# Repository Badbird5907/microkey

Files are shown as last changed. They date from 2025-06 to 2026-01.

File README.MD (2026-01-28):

# MicroKey
[Video Demo](https://youtube.com/shorts/Fg3U53FJ8HM)

Firmware can be found [here](https://github.com/Badbird5907/pico-fido-microkey)

This is a FIDO2 security key! It utilizes the RP2350A and [PicoKeys](https://picokeys.com) to implement FIDO2 U2F functionality! Unlike most picokeys, it uses a gold disc like the yubikey to detect touch instead of a tactile button.

I made this project because I saw the RP2350 could be used as a FIDO2 device with firmware like PicoKeys, and I couldn't find a yubikey-like device designed for PicoKeys. All the devices that were used were devboards, with tactile buttons and long USB cables.

front
back





# BOM
|Manufacturer |Description |Quantity|Unit Price($)|Ext.Price($)|Link |
|---|---|---|---|---|---|
|UNI-ROYAL(Uniroyal Elec) |62.5mW Thick Film Resistor 50V ±100ppm/℃ ±1% 1kΩ 0402 Chip Resistor - Surface Mount ROHS |100 |0.0006 |0.06 |https://lcsc.com/product-detail/chip-resistor-surface-mount_uni-royal-uniroyal-elec-0402wgf1001tce_C11702.html |
|Samsung Electro-Mechanics |16V 100nF X7R ±10% 0402 Multilayer Ceramic Capacitors MLCC - SMD/SMT ROHS |100 |0.0012 |0.12 |https://lcsc.com/product-detail/multilayer-ceramic-capacitors-mlcc-smd-smt_samsung-electro-mechanics-cl05b104ko5nnnc_C1525.html |
|FH (Guangdong Fenghua Advanced Tech)  |50V 15pF C0G ±5% 0402 Multilayer Ceramic Capacitors MLCC - SMD/SMT ROHS |100 |0.001 |0.1 |https://lcsc.com/product-detail/multilayer-ceramic-capacitors-mlcc-smd-smt_fh-guangdong-fenghua-advanced-tech-0402cg150j500nt_C1548.html|
|Samsung Electro-Mechanics |25V 10uF X5R ±10% 0805 Multilayer Ceramic Capacitors MLCC - SMD/SMT ROHS |20 |0.011 |0.22 |https://lcsc.com/product-detail/multilayer-ceramic-capacitors-mlcc-smd-smt_samsung-electro-mechanics-cl21a106kaynnne_C15850.html |
|Abracon LLC |SMD3225-4P Crystals ROHS |1 |0.3731 |0.37 |https://lcsc.com/product-detail/crystals_abracon-llc-abm8-272-t3_C20625731.html |
|Samsung Electro-Mechanics |10V 4.7uF X5R ±20% 0402 Multilayer Ceramic Capacitors MLCC - SMD/SMT ROHS |50 |0.0052 |0.26 |https://lcsc.com/product-detail/multilayer-ceramic-capacitors-mlcc-smd-smt_samsung-electro-mechanics-cl05a475mp5nrnc_C23733.html |
|UNI-ROYAL(Uniroyal Elec) |62.5mW Thick Film Resistor 50V ±100ppm/℃ ±1% 220Ω 0402 Chip Resistor - Surface Mount ROHS |100 |0.0006 |0.06 |https://lcsc.com/product-detail/chip-resistor-surface-mount_uni-royal-uniroyal-elec-0402wgf2200tce_C25091.html |
|UNI-ROYAL(Uniroyal Elec) |62.5mW Thick Film Resistor 50V ±100ppm/℃ ±1% 27Ω 0402 Chip Resistor - Surface Mount ROHS |100 |0.0006 |0.06 |https://lcsc.com/product-detail/chip-resistor-surface-mount_uni-royal-uniroyal-elec-0402wgf270jtce_C25100.html |
|UNI-ROYAL(Uniroyal Elec) |62.5mW Thick Film Resistor 50V ±100ppm/℃ ±1% 33Ω 0402 Chip Resistor - Surface Mount ROHS |100 |0.0006 |0.06 |https://lcsc.com/product-detail/chip-resistor-surface-mount_uni-royal-uniroyal-elec-0402wgf330jtce_C25105.html |
|UNI-ROYAL(Uniroyal Elec) |62.5mW Thick Film Resistor 50V ±100ppm/℃ ±1% 10kΩ 0402 Chip Resistor - Surface Mount ROHS |100 |0.0006 |0.06 |https://lcsc.com/product-detail/chip-resistor-surface-mount_uni-royal-uniroyal-elec-0402wgf1002tce_C25744.html |
|UNI-ROYAL(Uniroyal Elec) |62.5mW Thick Film Resistor 50V ±100ppm/℃ ±1% 5.1kΩ 0402 Chip Resistor - Surface Mount ROHS |100 |0.0005 |0.05 |https://lcsc.com/product-detail/chip-resistor-surface-mount_uni-royal-uniroyal-elec-0402wgf5101tce_C25905.html |
|Winbond Elec |16Mbit SPI 133MHz USON-8-EP(2x3) NOR FLASH ROHS |1 |0.6178 |0.62 |https://lcsc.com/product-detail/nor-flash_winbond-elec-w25q16jvuxiq_C2843335.html |
|Texas Instruments |65dB@(100kHz) 300mA Fixed 3.3V Positive 6V SOT-23-5 Voltage Regulators - Linear, Low Drop Out (LDO) Regulators ROHS|5 |0.201 |1.01 |https://lcsc.com/product-detail/voltage-regulators-linear-low-drop-out-ldo-regulators_texas-instruments-tps7a2033pdbvr_C2862740.html |
|XKB Connection |5A 1 12P Male -55℃~+85℃ Type-C SMD USB Connectors ROHS |1 |1.0428 |1.04 |https://lcsc.com/product-detail/usb-connectors_xkb-connection-u261-121n-4bs2s_C2879827.html |
|Raspberry Pi |QFN-60-EP(7x7) Microcontrollers (MCU/MPU/SOC) ROHS |1 |1.6544 |1.65 |https://lcsc.com/product-detail/microcontrollers-mcu-mpu-soc_raspberry-pi-rp2350a_C42411118.html |
|Abracon LLC |0806 Power Inductors ROHS |5 |0.2584 |` |https://lcsc.com/product-detail/power-inductors_abracon-llc-aota-b201610s3r3-101-t_C42411119.html |
|Kingbright |SMD3528-4P RGB LEDs ROHS |1 |1.6213 |1.62 |https://lcsc.com/product-detail/rgb-leds_kingbright-aaa3528rbgs-08-09_C6851380.html |
|Shipping | | | |11.71 | |
|Handling Fee | | | |3 | |
|PCB (expensive bc ENIG + edge plating)| | | |67.28 | |
|Stencil | | | |7.48 | |
|JLC Shipping | | | |7.78 | |
|TOTAL | | | |104.61 | |

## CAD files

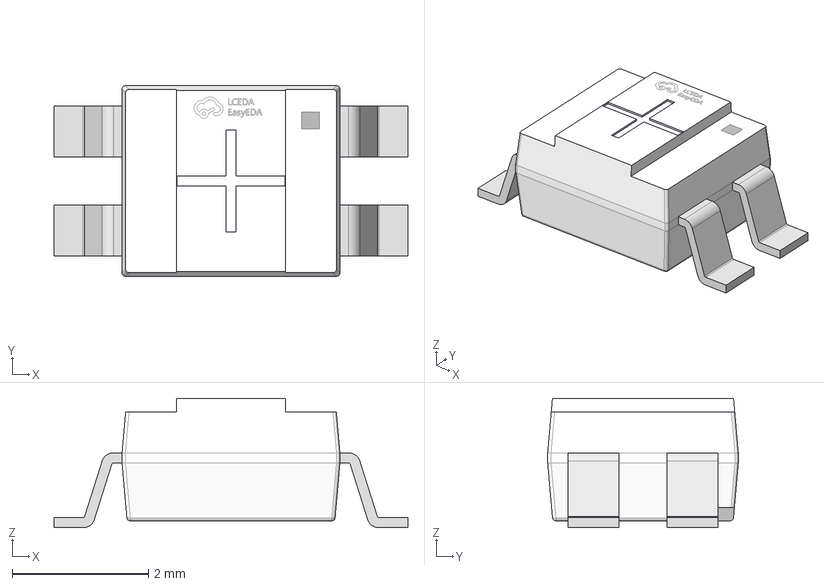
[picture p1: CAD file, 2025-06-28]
PCB/Components/LED-SMD_4P-L3.2-W2.8_XZMDKCBDDG45S-9.step
5.20 x 2.80 x 1.90 mm

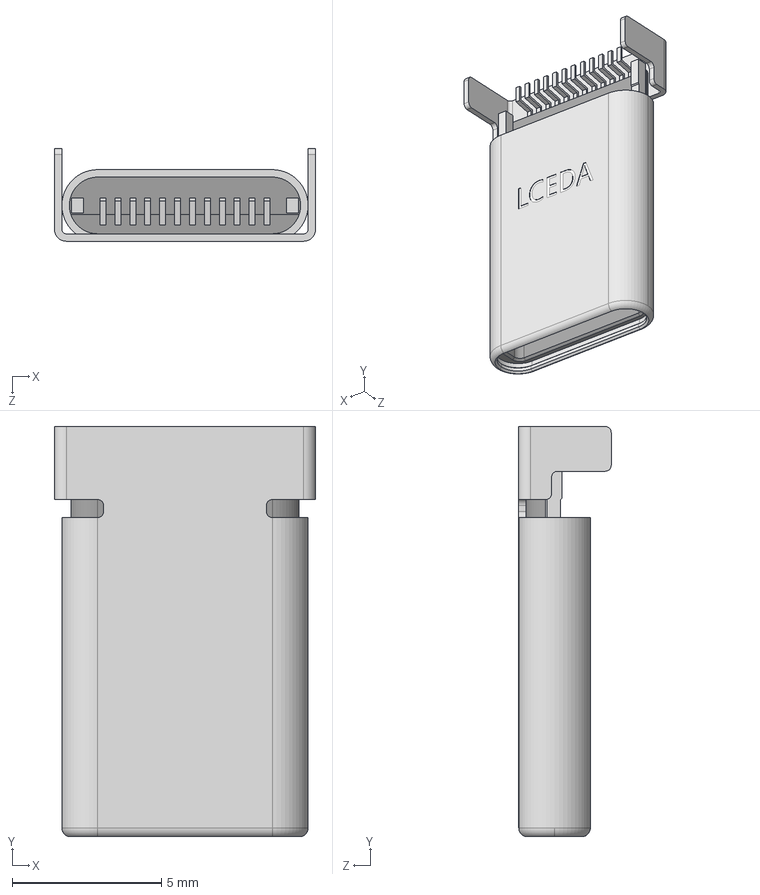
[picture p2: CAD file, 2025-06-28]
PCB/Components/USB-C-SMD_U261-121N-4BS2S.step
8.75 x 13.7 x 3.10 mm

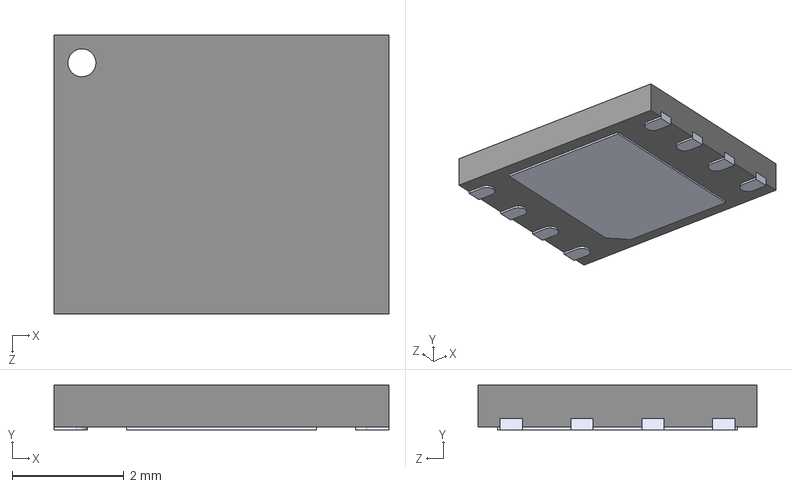
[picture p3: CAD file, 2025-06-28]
PCB/Components/W25Q16JVZPIQ.step
6.00 x 0.8 x 5.00 mm

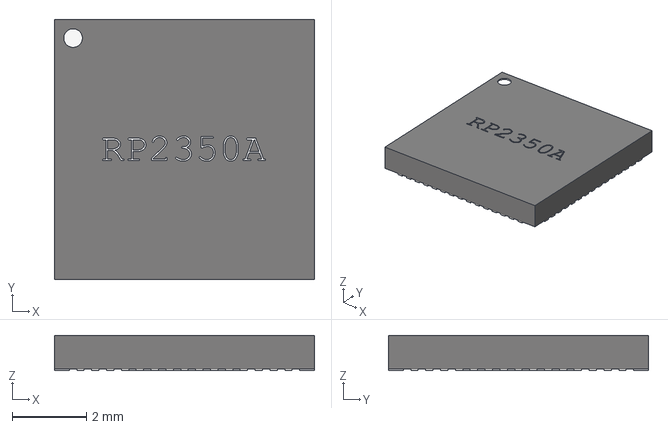
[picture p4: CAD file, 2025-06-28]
PCB/Components/RP2350_QFN60.step
7.00 x 7.00 x 0.95 mm

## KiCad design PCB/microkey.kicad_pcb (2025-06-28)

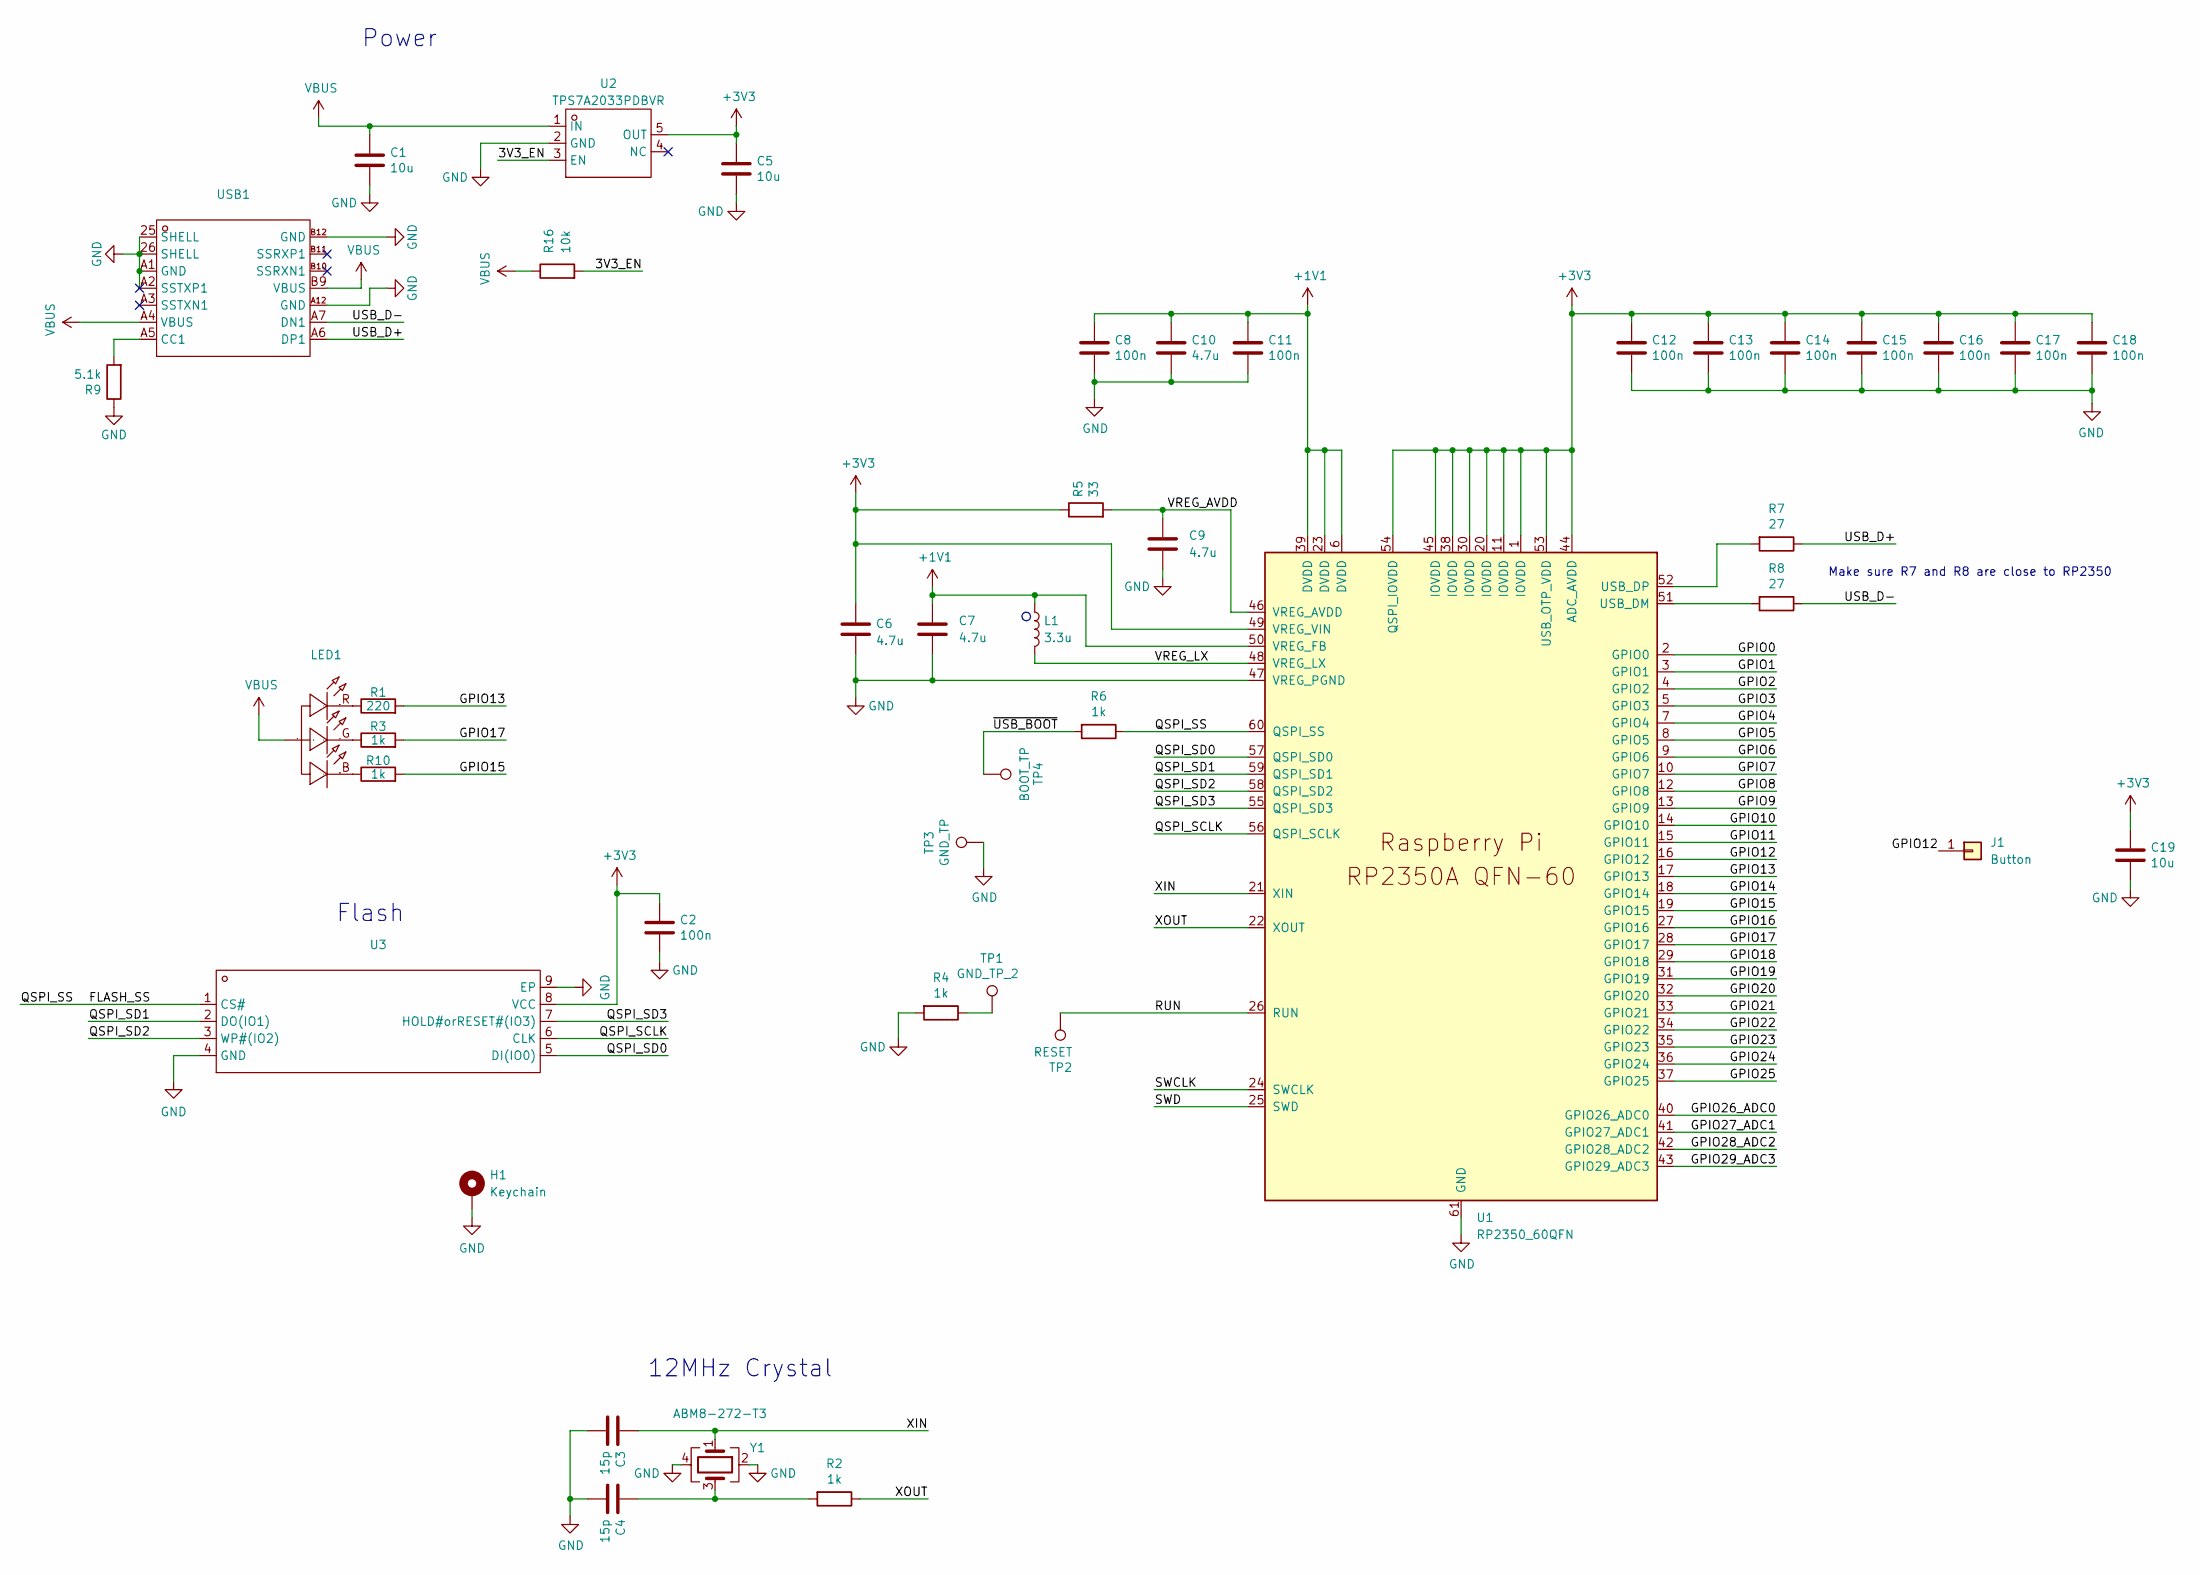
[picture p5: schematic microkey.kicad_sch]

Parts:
C1, C5, C19: 10u; C_0805_2012Metric
C2, C8, C11, C12, C13, C14, C15, C16, C17, C18: 100n; C_0402_1005Metric
C3, C4: 15p; C_0402_1005Metric
C6, C7: 4.7u; C_0402_1005Metric_small_pads
C9, C10: 4.7u; C_0402_1005Metric
H1: Keychain
J1: Button
L1: 3.3u; L_pol_2016
LED1: LED-SMD_4P-L3.2-W2.8_XZMDKCBDDG45S-9; Manufacturer Part AAA3528RBGS/08-09; LCSC Part Name AAA3528RBGS/08-09
R1: 220; R_0402_1005Metric
R2, R3, R4, R6, R10: 1k; R_0402_1005Metric
R5: 33; R_0402_1005Metric
R7, R8: 27; R_0402_1005Metric
R9: 5.1k; R_0402_1005Metric
R16: 10k; R_0402_1005Metric
TP1: GND_TP_2; TestPoint_Pad_D1.0mm
TP2: RESET; TestPoint_Pad_D1.0mm
TP3: GND_TP; TestPoint_Pad_D1.0mm
TP4: BOOT_TP; TestPoint_Pad_D1.0mm
U1: RP2350_60QFN; RP2350-QFN-60-1EP_7x7_P0.4mm_EP3.4x3.4mm_ThermalVias
U2: TPS7A2033PDBVR; SOT-23-5_L2.9-W1.6-P0.95-LS2.8-BR; Manufacturer Part TPS7A2033PDBVR; LCSC Part Name 具有高 PSRR 的 300mA、超低噪声、低 IQ、低压降 (LDO) 线性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
U3: USON-8_L3.0-W2.0-P0.50-BL-EP; Manufacturer Part W25Q16JVUXIQ; LCSC Part Name W25Q16JVUXIQ
USB1: USB-C-SMD_U261-121N-4BS2S; Manufacturer Part U261-121N-4BS2S; LCSC Part Name Type-C 公
Y1: ABM8-272-T3; Crystal_SMD_3225-4Pin_3.2x2.5mm

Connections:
+1V1: C7.1, C8.1, C10.1, C11.1, L1.1, U1.6 (DVDD), U1.23 (DVDD), U1.39 (DVDD), U1.50 (VREG_FB)
+3V3: C2.1, C5.1, C6.1, C12.1, C13.1, C14.1, C15.1, C16.1, C17.1, C18.1, C19.1, R5.1, U1.1 (IOVDD), U1.11 (IOVDD), U1.20 (IOVDD), U1.30 (IOVDD), U1.38 (IOVDD), U1.44 (ADC_AVDD), U1.45 (IOVDD), U1.49 (VREG_VIN), U1.53 (USB_OTP_VDD), U1.54 (QSPI_IOVDD), U2.5 (OUT), U3.8 (VCC)
/3V3_EN: R16.2, U2.3 (EN)
/FLASH_SS: R6.1, U1.60 (QSPI_SS), U3.1 (CS#)
/GPIO0: U1.2 (GPIO0)
/GPIO1: U1.3 (GPIO1)
/GPIO2: U1.4 (GPIO2)
/GPIO3: U1.5 (GPIO3)
/GPIO4: U1.7 (GPIO4)
/GPIO5: U1.8 (GPIO5)
/GPIO6: U1.9 (GPIO6)
/GPIO7: U1.10 (GPIO7)
/GPIO8: U1.12 (GPIO8)
/GPIO9: U1.13 (GPIO9)
/GPIO10: U1.14 (GPIO10)
/GPIO11: U1.15 (GPIO11)
/GPIO12: J1.1, U1.16 (GPIO12)
/GPIO13: R1.2, U1.17 (GPIO13)
/GPIO14: U1.18 (GPIO14)
/GPIO15: R10.2, U1.19 (GPIO15)
/GPIO16: U1.27 (GPIO16)
/GPIO17: R3.2, U1.28 (GPIO17)
/GPIO18: U1.29 (GPIO18)
/GPIO19: U1.31 (GPIO19)
/GPIO20: U1.32 (GPIO20)
/GPIO21: U1.33 (GPIO21)
/GPIO22: U1.34 (GPIO22)
/GPIO23: U1.35 (GPIO23)
/GPIO24: U1.36 (GPIO24)
/GPIO25: U1.37 (GPIO25)
/GPIO26_ADC0: U1.40 (GPIO26_ADC0)
/GPIO27_ADC1: U1.41 (GPIO27_ADC1)
/GPIO28_ADC2: U1.42 (GPIO28_ADC2)
/GPIO29_ADC3: U1.43 (GPIO29_ADC3)
/QSPI_SCLK: U1.56 (QSPI_SCLK), U3.6 (CLK)
/QSPI_SD0: U1.57 (QSPI_SD0), U3.5 (DI(IO0))
/QSPI_SD1: U1.59 (QSPI_SD1), U3.2 (DO(IO1))
/QSPI_SD2: U1.58 (QSPI_SD2), U3.3 (WP#(IO2))
/QSPI_SD3: U1.55 (QSPI_SD3), U3.7 (HOLD#orRESET#(IO3))
/RUN: TP2.1, U1.26 (RUN)
/SWCLK: U1.24 (SWCLK)
/SWD: U1.25 (SWD)
/USB_D+: R7.1, USB1.A6 (DP1)
/USB_D-: R8.1, USB1.A7 (DN1)
/VREG_AVDD: C9.1, R5.2, U1.46 (VREG_AVDD)
/VREG_LX: L1.2, U1.48 (VREG_LX)
/XIN: C3.1, U1.21 (XIN), Y1.1
/XOUT: R2.1, U1.22 (XOUT)
/~USB_BOOT: R6.2, TP4.1
GND: C1.2, C2.2, C3.2, C4.2, C5.2, C6.2, C7.2, C8.2, C9.2, C10.2, C11.2, C12.2, C13.2, C14.2, C15.2, C16.2, C17.2, C18.2, C19.2, H1.1, R4.2, R9.1, TP3.1, U1.47 (VREG_PGND), U1.61 (GND), U2.2 (GND), U3.4 (GND), U3.9 (EP), USB1.25 (SHELL), USB1.26 (SHELL), USB1.A1 (GND), USB1.A2 (SSTXP1), USB1.A12 (GND), USB1.B12 (GND), Y1.2, Y1.4
unnamed: C4.1, R2.2, Y1.3
unnamed: LED1.1 (-), R1.1
unnamed: LED1.3 (-), R3.1
unnamed: LED1.4 (-), R10.1
unnamed: R4.1, TP1.1
unnamed: R8.2, U1.51 (USB_DM)
unnamed: R7.2, U1.52 (USB_DP)
unnamed: R9.2, USB1.A5 (CC1)
VBUS: C1.1, LED1.2 (+), R16.1, U2.1 (IN), USB1.A4 (VBUS), USB1.B9 (VBUS)

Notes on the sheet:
Power
Make sure R7 and R8 are close to RP2350
12MHz Crystal
Flash

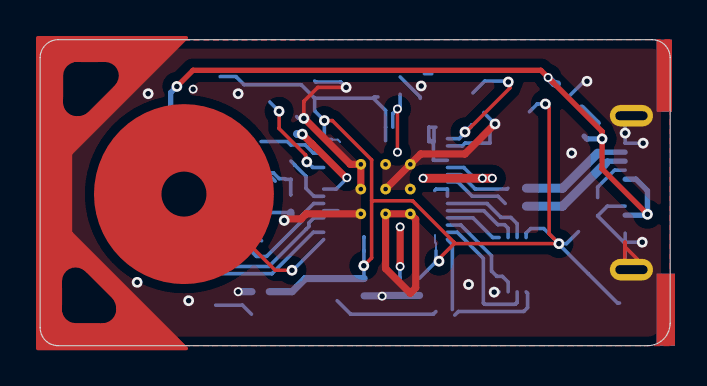
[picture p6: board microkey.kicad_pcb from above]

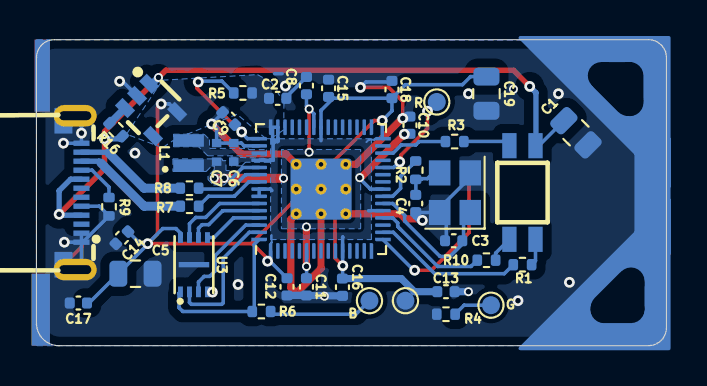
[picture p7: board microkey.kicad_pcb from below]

Board: 2 copper layers, 35.0 x 17.0 mm, 43 parts (41 on the bottom side), 31 nets.

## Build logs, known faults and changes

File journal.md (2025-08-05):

Total time spent: 33h

# 6/26
Time spent: 1h

Played around with one of my rpi picos and figured out how to detect touch on just a wire. (Capacitive touch)
You can do this by measuring the capacitance of the wire and then using a threshold to determine if it is being touched.

# 6/27
Time spent: 7h
Created the schematic and PCB that integrates the RP2350A and a capacitive touch pad in the formfactor of a Yubikey.


---
Time spent: 2h
Sourced parts and created BOM
---
Time spent: 3h
I decided to add a keyring hole, and that took FOREVER because I wanted a triangle in the corner, that's plated on the inside, which meant I needed to get creative with pads.
I did finally get it to work, though.


I then decided to swap out the led for something that would shine thru the pcb, so I spent forever finding the perfect led that has the right dimensions, and was in a gullwing package. I finally found the AAA3528RBGS, which is also in stock at LCSC! I then spent a LOT of time redesigning the button footprint (KICAD'S FOOTPRINT EDITOR SUCKS) to include a hole with no copper and only fiberglass, and then redesigning the clock section of the PCB to accommodate the new led footprint.

**TOTAL TIME TODAY:** 12h (I literally spent the whole day and night on this, it's 4am now)

# 6/28
Time spent: 1h
Optimized some traces, redid BOM
---
Time spent: 1h
Added edge plating, redid BOM

# 7/20-7/22
Time spent: 18h
Assembled parts and reflowed them all onto the PCB.
I then spent forever developing firmware for the capacitve touch sensor, and finally got it working.




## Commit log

2025-06-28 readme and bom
    [AAA3528-09.STEP, BOM-microkey.csv, BOM.csv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]
2025-06-28 edge plating!!
    [BOM.csv, microkey.kicad_pcb]
2025-06-28 readme images
    [CPL-microkey.csv, microkey-CuBottom.gbr, microkey-CuTop.gbr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]
2025-06-30 Update bom and readme
    [BOM.csv]
